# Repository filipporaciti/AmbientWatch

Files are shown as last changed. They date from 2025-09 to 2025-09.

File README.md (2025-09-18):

# 📌 AmbientWatch

## 📖 Descrizione
Il dispositivo permette per monitorare alcuni parametri ambientali (co2, temperatura, umidità, rumore), visualizzarli su un display e mandarli su un server MQTT. È inoltre dotato di un buzzer per segnalare eventuali parametri critici. 

## 🛠️ Hardware utilizzato
- **ESP32**
- **SCD41**: sensore co2, umidità, temperatura
- **INMP441**: microfono
- **SSD1306**: display oled
- **Encoded trigger**
- **Buzzer**
- **Batterie da 3.7V**
- **TP4056**: modulo per caricare le batterie
- **Modulo step-up da 3.7V a 5V**

## 📦 Librerie

```c
#include <Preferences.h>
#include <ESP32Encoder.h>
#include <Wire.h>
#include <Adafruit_SSD1306.h>
#include <Fonts/TomThumb.h>
#include <SensirionI2cScd4x.h>
#include <PubSubClient.h>
#include <WiFi.h>
#include <driver/i2s.h>
#include <Arduino.h>
```

## 🔧 Installazione
⚠️ ATTENZIONE!!! <br>
Il sensore SCD41 potrebbe aver bisogno di essere configurato; in tal caso consultare la libreria [SensirionI2cScd4x](https://github.com/Sensirion/arduino-i2c-scd4x/blob/master/src/SensirionI2cScd4x.h).

Allo stesso modo il microfono potrebbe aver bisogno di essere configurato; in questo caso modificare la costante `DECIBEL_CALIB_OFFSET` nel file [INMP441.h](AmbientWatch/INMP441.h).

Prima di caricare il firmware, bisogna configurare il WiFi e il server MQTT; per farlo basta rinominare il file nella directory [AmbientWatch](AmbientWatch) da `secrets.h.example` a `secrets.h`, aprire il file e impostare correttamente tutti i parametri richiesti.

Una volta configurati tutti i parametri, si può caricare il firmware utilizzando Arduino IDE.

Per quanto riguarda tutti i vari collegamenti, ecco lo schema:

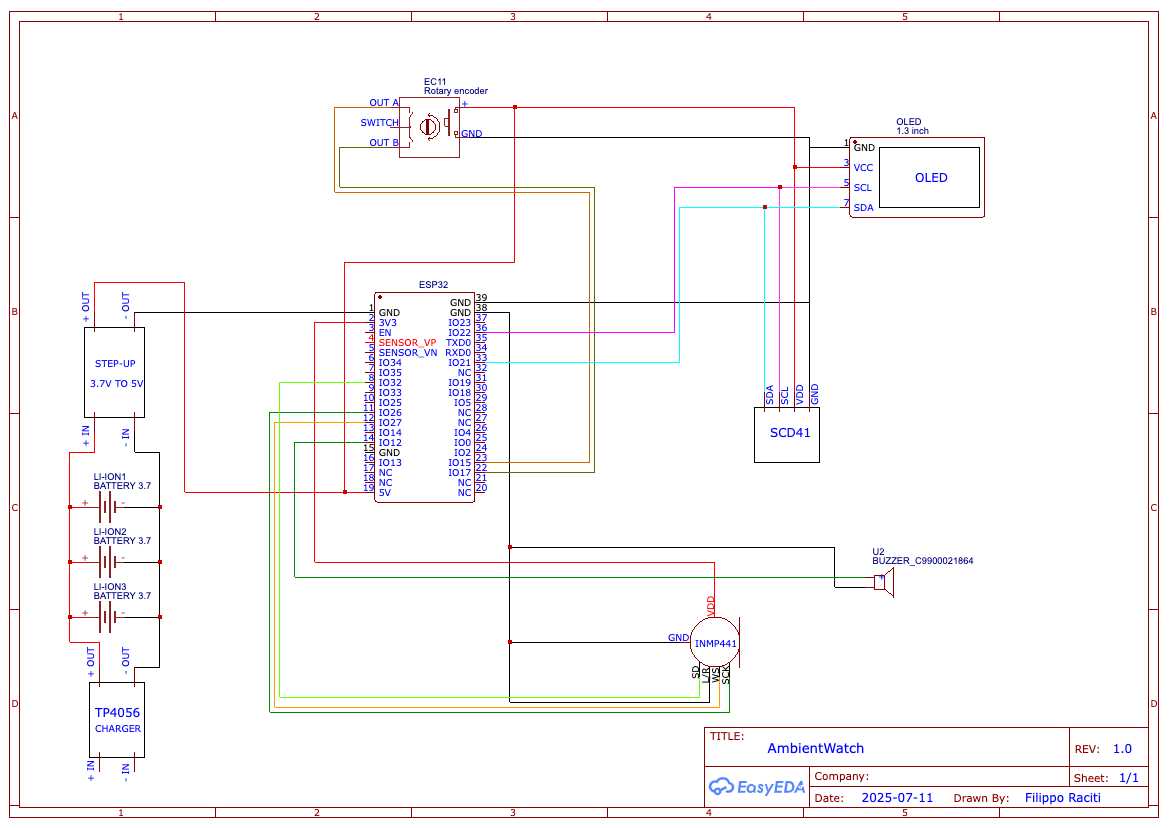
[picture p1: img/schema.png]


## 🔌 Consumo energetico
Facciamo una stima di quanto tempo duri la batteria per alimentare il sistema in maniera continuativa (consideriamo solamente il caso in cui non risvegli l'esp32 dalla sleep mode, ovvero quando non uso l'encoder rotativo per cambiare la schermata del display)

Io ho usato 3 batterie da 1330 mAh l'una.

Il consumo medio del sistema lo possiamo dividere in due fasi:
- Esp32 non in sleep mode: mediamente consuma 90 mA per ~90 s
- Esp32 in sleep mode: consuma 22 mA per ~210 s 
Quindi il consumo medio sarà di $`\dfrac{(90*90)+(22*210)}{300}=42.4`$

Le batterie sono da 1330 mAh l'una, collegate in parallelo --> 3990 mAh.

Quest'ultime erogano una tensione di 3.7V e sono collegate ad uno step-up per alzare e tenere stabile la tensione a 5V. 
Per calcolare il consumo dello step-up dobbiamo trovare la potenza in uscita necessaria con i 5V, e poi verificare la corrente necessaria con i 3.7V. <br>
Inoltre bisogna tenere in considerazione l'efficienza del modulo (circa del 90%) e il suo consumo fisso (2 mA). Quindi: 

Calcolo potenza in uscita dal modulo:<br>
$`P_{out} = 5 V * 0.0424 A ~= 0.212 W`$

Calcolo potenza in entrata dal modulo (quindi devo aggiungere il 10% dato che ha un'efficienza del 90%):<br>
$`P_{in} = 0.212 W + \dfrac{0.212 W * 10}{100} ~= 0.233 W`$

Calcolo corrente entrata con 3.7V:<br>
$`I_{in} = \dfrac{0.233 W}{3.7 V} ~= 0.063 A ~= 63 mA`$

Aggiungo il costo costante del modulo di 2mA:<br>
$`I_{totale} = 63 mA + 2 mA ~= 65 mA`$

**$`Autonomia = \dfrac{3990 mAh}{65 mA} ~= 61.4 h`$**

## ❌ Problemi noti
- Ho dovuto collegare il GND dal modulo step-up all'ESP32 direttamente nello spinotto usb dell'ESP32, altrimenti non sarebbe riuscito a ricevere la corrente necessaria per il suo funzionamento.
- Se uso l'encoded trigger mentre l'ESP32 si trova in light sleep mode, il primo valore catturato dal programma potrebbe non essere quello aspettato; questo accade perchè ESP32  perde delle informazioni per triggerare l'uscita dallo sleep mode.

## 📸 Foto
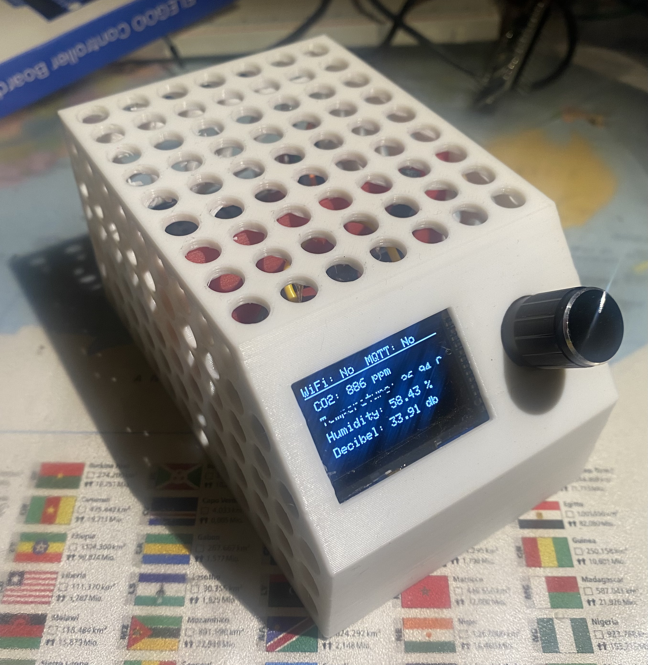
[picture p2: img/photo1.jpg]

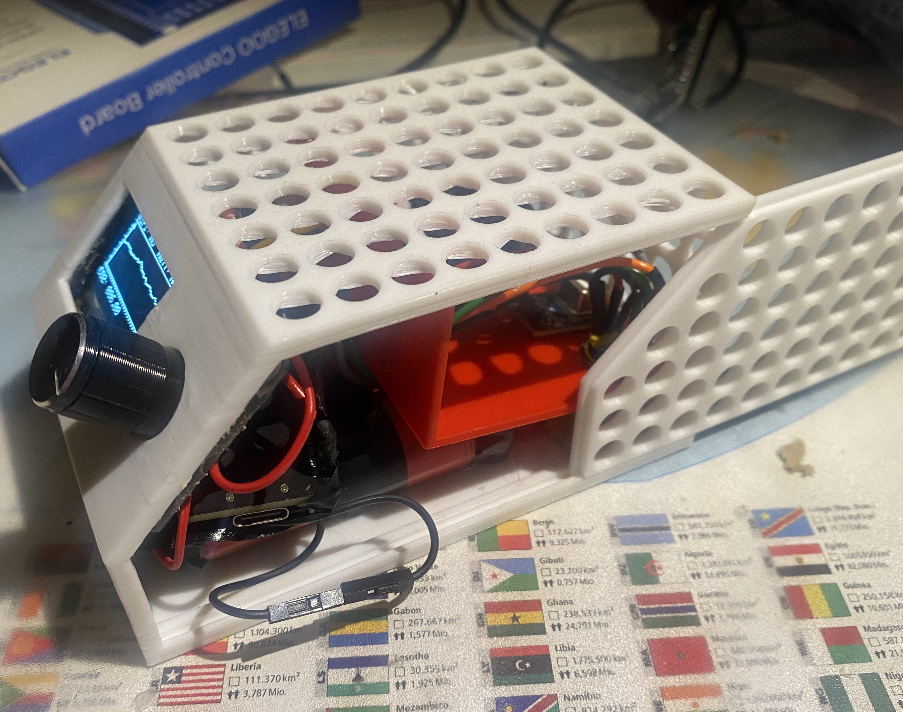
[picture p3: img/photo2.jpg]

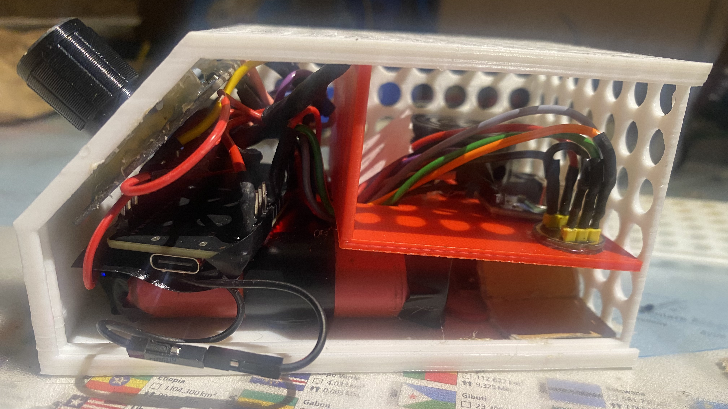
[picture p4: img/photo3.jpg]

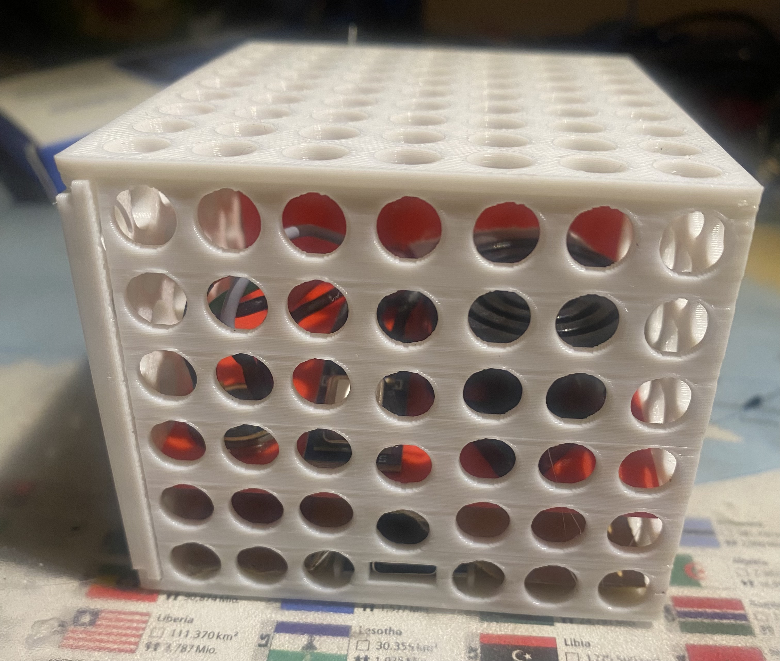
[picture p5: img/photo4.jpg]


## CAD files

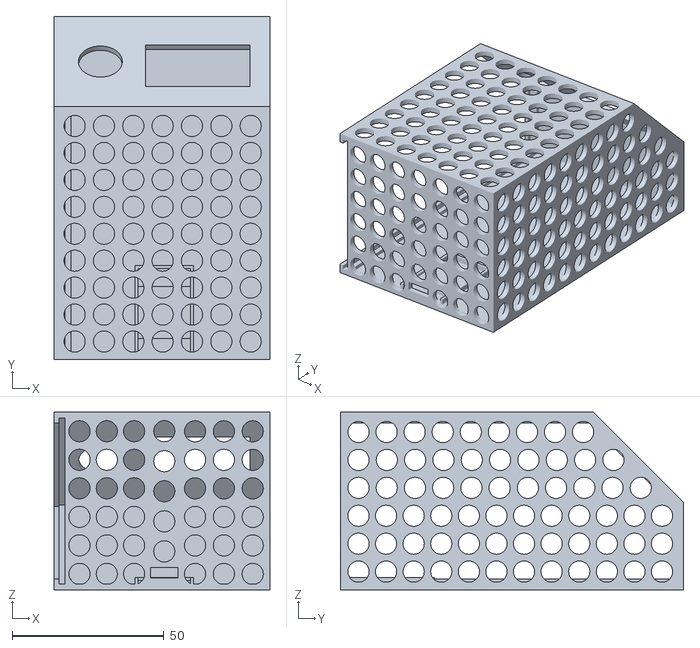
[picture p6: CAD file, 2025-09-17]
case/case.stl
71.0 x 113.0 x 58.5

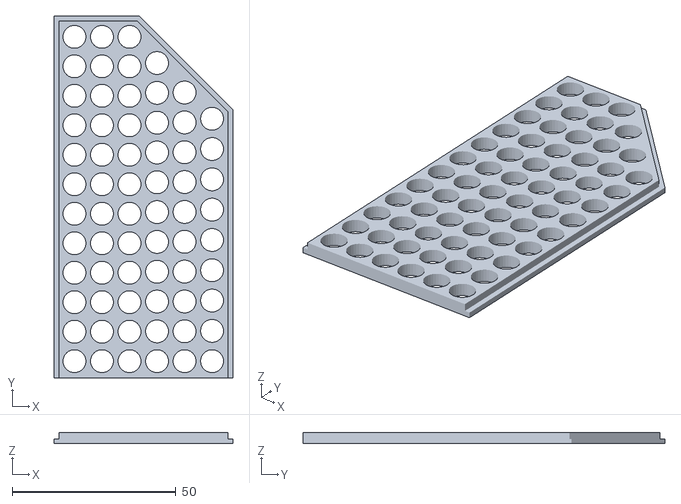
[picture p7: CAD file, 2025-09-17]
case/porta.stl
54.5 x 110.5 x 3.50

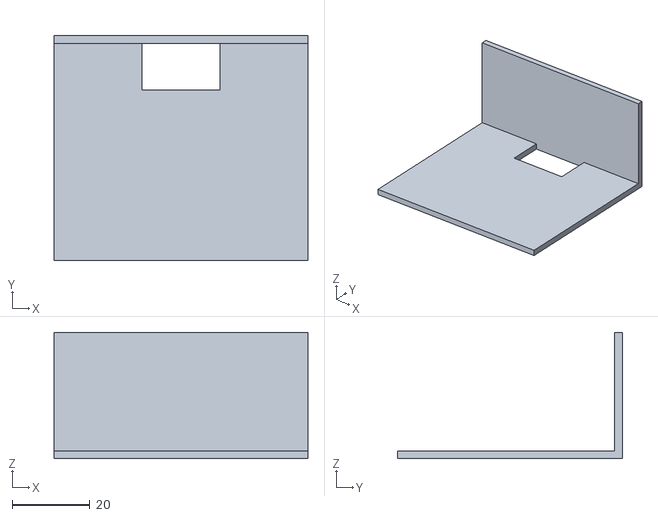
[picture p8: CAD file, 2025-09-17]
case/separatore.stl
65.5 x 58.0 x 32.5

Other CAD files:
case/AmbientWatch_case.f3d

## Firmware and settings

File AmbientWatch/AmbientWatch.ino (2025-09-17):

#include <Preferences.h>
#include <ESP32Encoder.h>
#include <Wire.h>
#include "DataDisplay.h"
#include "WiFi_MQTT.h"
#include "INMP441.h"
#include "SCD41.h"
#include "secrets.h"

#define TRA 15
#define TRB 17
#define BUZZER_PIN 12

#define LIGHT_SLEEP_TIME 60000 * 5

#define MQTT_TOPIC_SUBSCRIBE "esame/pippo/alert_limits/#"
#define MQTT_PUBLISH_ALERT_SOFT "esame/pippo/alert_limits/soft"
#define MQTT_PUBLISH_ALERT_STRONG "esame/pippo/alert_limits/strong"
#define MQTT_PUBLISH_ALERT_STATUS_SOFT "esame/pippo/alert_status/soft"
#define MQTT_PUBLISH_ALERT_STATUS_STRONG "esame/pippo/alert_status/strong"
#define MQTT_PUBLISH_DATA "esame/pippo/data"

TaskHandle_t core0TaskHandle = NULL;

static IRAM_ATTR void resumeDisplayTask(void* arg) {
  if (core0TaskHandle != NULL) {
    vTaskResume(core0TaskHandle);
  }
}

uint16_t co2 = 0;
float temperature = 0.0;
float humidity = 0.0;
float decibel = 0.0;

bool co2_alert = false;
bool temperature_alert = false;
bool humidity_alert = false;
bool decibel_alert = false;

uint16_t soft_co2_max = 0; 
float soft_temp_min = 0;
float soft_temp_max = 0;
float soft_hum_min = 0;
float soft_hum_max = 0;
float soft_dec_max = 0;

uint16_t strong_co2_max = 0; 
float strong_temp_min = 0;
float strong_temp_max = 0;
float strong_hum_min = 0;
float strong_hum_max = 0;
float strong_dec_max = 0;

bool sound_alert = false;

const int numValues = 31;

float co2Values[numValues] = { 0 };
float co2MaxVal = co2;

float tempValues[numValues] = { 0 };
float tempMaxVal = temperature;

float humValues[numValues] = { 0 };
float humMaxVal = humidity;

float decValues[numValues] = { 0 };
float decMaxVal = decibel;

SCD41 sensor;
DataDisplay display;
WiFi_MQTT client(WIFI_SSID, WIFI_PASSWORD, MQTT_IP);
INMP441 decibelSensor;

Preferences prefs;

ESP32Encoder encoder(true, resumeDisplayTask);

long oldPosition = -999;
int encoderValue = 0;

void core0Task(void* parameter) {
  encoderTrigger();
}

void setup() {
  Serial.begin(115200);
  while (!Serial) {
    delay(100);
  }
  Serial.println("");

  loadAlertSettings();
  
  pinMode(BUZZER_PIN, OUTPUT);

  encoder.attachSingleEdge(TRA, TRB);
  encoder.clearCount();

  Wire.begin();

  if (!display.begin()) {
    Serial.println("ERROR: Display begin error");
    for (;;);
  }
  display.clearDisplay(); // stampo schermo nero
  display.display();

  client.connect(MQTT_TOPIC_SUBSCRIBE);
  client.setCallback(callback);
  client.publishAlertLimits(MQTT_PUBLISH_ALERT_SOFT, soft_co2_max, soft_temp_min, soft_temp_max, soft_hum_min, soft_hum_max, soft_dec_max);
  client.publishAlertLimits(MQTT_PUBLISH_ALERT_STRONG, strong_co2_max, strong_temp_min, strong_temp_max, strong_hum_min, strong_hum_max, strong_dec_max);
  client.disconnect();
  
  // lo stampo dopo in questo modo se la batteria è scarica mostra solo lo schermo nero e non quello dei dati lampeggianti
  display.clearDisplay();
  display.printConnectionStatus(false, false);
  display.printValues(co2, temperature, humidity, decibel, false, false, false, false);
  display.display();

  if (!sensor.begin()) {
    Serial.println("ERROR: SCD41 sensor error begin");
    for (;;);
  }

  xTaskCreatePinnedToCore(
    core0Task,         // nome funzione
    "core0Task",       // nome task
    4096,              // grandezza stack
    NULL,              // parametri
    1,                 // priorità
    &core0TaskHandle,  // handle
    0                  // Core 0
  );

}

void loop() {
  Serial.println("----- Start loop -----");

  unsigned long mill_start = millis();

  // ----- Reading data -----
  Serial.print("Reading co2, temperature, humidity values...");
  sensor.getValues(co2, temperature, humidity);
  pushInCoda(co2Values, (float)co2, numValues);
  pushInCoda(tempValues, temperature, numValues);
  pushInCoda(humValues, humidity, numValues);
  if (tempMaxVal < temperature) {
    tempMaxVal = temperature;
  }
  if (co2MaxVal < co2) {
    co2MaxVal = co2;
  }
  if (humMaxVal < humidity) {
    humMaxVal = humidity;
  }
  Serial.println("end");

  Serial.print("Reading decibel...");
  decibel = decibelSensor.readAvgValue();
  pushInCoda(decValues, decibel, numValues);
  if (decMaxVal < decibel) {
    decMaxVal = decibel;
  }
  Serial.println("end");

  Serial.print("CO2: ");
  Serial.print(co2);
  Serial.println(" ppm");

  Serial.print("Environment temperature : ");
  Serial.print(temperature);
  Serial.println(" C");

  Serial.print("Relative humidity : ");
  Serial.print(humidity);
  Serial.println(" RH");

  Serial.print("Decibel : ");
  Serial.print(decibel);
  Serial.println(" db");
  // ----- End reading data -----

  checkValues();

  // ----- MQTT -----
  client.connect(MQTT_TOPIC_SUBSCRIBE);
  client.publishData(MQTT_PUBLISH_DATA, co2, temperature, humidity, decibel);
  client.updateSubscribe();
  saveAlertSettings(); // se ci sono stati aggironamenti, li salvo
  // client.publishSoftAlertLimits(soft_co2_max, soft_temp_min, soft_temp_max, soft_hum_min, soft_hum_max, soft_dec_max); // potrei metterli per eliminare i retain
  // client.publishStrongAlertLimits(strong_co2_max, strong_temp_min, strong_temp_max, strong_hum_min, strong_hum_max, strong_dec_max);
  client.publishAlertStatus(MQTT_PUBLISH_ALERT_STATUS_SOFT, co2_alert || temperature_alert || humidity_alert || decibel_alert);
  client.publishAlertStatus(MQTT_PUBLISH_ALERT_STATUS_STRONG, sound_alert);
  client.disconnect();
  // ----- End MQTT -----

  updateDisplay();

  if (!(co2_alert || temperature_alert || humidity_alert || decibel_alert || sound_alert)) {  // se non ho alert allora posso andare il sleep, altrimenti aggiorno i valori
    while (eTaskGetState(core0TaskHandle) != eSuspended) { // aspetta che il task abbia finito
      delay(70);
    }
    unsigned long m = millis();
    unsigned long sleep_time = LIGHT_SLEEP_TIME - (m - mill_start);
    if (sleep_time < 0 || sleep_time > LIGHT_SLEEP_TIME) {
      sleep_time = LIGHT_SLEEP_TIME;
    }
    anyway_sleep_timer(sleep_time);
  }
}

/*
Fa andare l'esp32 in light sleep mode per il tempo impostato dal parametro time_sleep. 
L'esp32 può uscire dalla sleep mode attraverso un interrupt oppure quando il tempo è terminato.
In caso l'esp32 esca dalla sleep mode attraverso l'interrupt, la funzione si occuperà di rimettere l'esp32 in sleep mode appena possibile fino alla fine del tempo prestabilito.

@param time_sleep tempo in cui l'esp32 dovrà stare in sleep mode
*/
void anyway_sleep_timer(unsigned long time_sleep) {
  unsigned long m_start = 0;
  unsigned long time_left = time_sleep;

  while (time_left > 1000) {  // qualche millisecondo di range per evitare falsi positivi
    Serial.print("Light sleep mode. Time left: ");
    Serial.println(time_left);
    Serial.flush();

    m_start = millis();
    esp_sleep_enable_ext0_wakeup(GPIO_NUM_15, 0);
    esp_sleep_enable_timer_wakeup(time_left * 1000);  // vuole microsecondi come parametro
    esp_light_sleep_start();

    resumeDisplayTask(NULL);
    while (eTaskGetState(core0TaskHandle) != eSuspended) { // aspetta che il task abbia finito
      delay(70);
      m_start += 70;
    }

    unsigned long m_now = millis();
    unsigned long sleep = time_left - (m_now - m_start);  // vedo quanto è passato
    if (time_left < m_now - m_start) {
      sleep = 0;
    }

    if (sleep > time_left || m_now < m_start) {  // per eventuali overflow
      Serial.println("Timer reset");
      time_left = 0;
    } else {
      time_left = sleep;
    }
  }
}

/*
Serve per gestire l'encoder e l'aggiornamento del display.
*/
void encoderTrigger() {
  while (true) {
    unsigned long encoderTime = millis();

    while (millis() - encoderTime < 1000) {
      long newPosition = encoder.getCount();
      if (newPosition != oldPosition) {
        encoderTime = millis(); // resetto il tempo di fine task (se non ci sono valori critici)
        oldPosition = newPosition;
        encoderValue = newPosition;
        if (encoderValue < 0) { // il modulo di un numero negativo lo tratta come se fosse positivo :(
          int x = (abs(encoderValue)/5)+1;
          encoderValue += 5*x;
        }
        encoderValue = (encoderValue) % 5;
        Serial.print("Display position: ");
        Serial.println(encoderValue);
        // il display devo aggiornarlo almeno una volta, e in caso ci sia un alert tutte le volte finchè non termina l'alert
        do {
          if (co2_alert || temperature_alert || humidity_alert || decibel_alert) encoderValue = 0;
          checkValues();
          printDisplay();
        } while (co2_alert || temperature_alert || humidity_alert || decibel_alert);
      }
      yield();  // per evitare il watchdog. yield permette di lasciare la CPU ad altri task
    }
    Serial.println("Display task suspend");
    vTaskSuspend(core0TaskHandle);
    Serial.println("Display task resume");
  }
}

/*
Aggiorna il display.
*/
void updateDisplay() {
  oldPosition = -999;
  resumeDisplayTask(NULL);
}

/*
Visualizza le informazioni nel display in base al valore dell'encoder in quel momento.
*/
void printDisplay() {
  display.clearDisplay();
  display.printConnectionStatus(client.wifiStatus, client.mqttStatus);
  if (encoderValue == 0) {
    display.printValues(co2, temperature, humidity, decibel, co2_alert, temperature_alert, humidity_alert, decibel_alert);
  } else if (encoderValue == 1) {
    display.printGraph("Decibel: ", decValues, numValues, decMaxVal);
  } else if (encoderValue == 2) {
    display.printGraph("Humidity: ", humValues, numValues, humMaxVal);
  } else if (encoderValue == 3) {
    display.printGraph("Temperature: ", tempValues, numValues, tempMaxVal);
  } else if (encoderValue == 4) {
    display.printGraph("CO2: ", co2Values, numValues, co2MaxVal);
  } else {
    display.clearDisplay();
    display.display();
  }
}

/*
Dato un'array, la funzione mette l'elemento in posizione i nella posizione i-1.
L'elemento in posizione 0 verrà eliminato mentre l'elemento nell'ultima posizione sarà il parametro newVal.

@param arr array da modificare
@param newVal nuovo valore che verrà posizionato in posizione len-1
@param len lunghezza array
*/
void pushInCoda(float* arr, float newVal, int len) {
  for (int i = 0; i < len - 1; i++) {
    arr[i] = arr[i + 1];
  }
  arr[len - 1] = newVal;
}

/*
Controlla che i valori non superino i soft e strong limit e imposta le variabili degli alert a true se li supera, altrimenti a false. 
La funzione inoltre attiva e disattiva il buzzer in caso i valori superino gli strong limit.
*/
void checkValues() {
  if (co2 != 0 && temperature != 0 && humidity != 0) { // in caso non siano stati presi i valori, non faccio il check dei valori
    co2_alert = co2 > soft_co2_max;
    temperature_alert = temperature < soft_temp_min || temperature > soft_temp_max;
    humidity_alert = humidity < soft_hum_min || humidity > soft_hum_max;
    decibel_alert = decibel > soft_dec_max;
    sound_alert = co2 > strong_co2_max || temperature < strong_temp_min || temperature > strong_temp_max || humidity < strong_hum_min || humidity > strong_hum_max;
    if (sound_alert) {
      digitalWrite(BUZZER_PIN, HIGH); 
    } else {
      digitalWrite(BUZZER_PIN, LOW);    
    }
  }
}

/*
Salva in maniera persistente i soft e strong limit dalle variabili corrispondenti.
*/
void saveAlertSettings() {
  prefs.begin("AmbientWatch", false); // false = scrittura

  prefs.putUShort("soft_co2_max", soft_co2_max);
  prefs.putFloat("soft_temp_min", soft_temp_min);
  prefs.putFloat("soft_temp_max", soft_temp_max);
  prefs.putFloat("soft_hum_min", soft_hum_min);
  prefs.putFloat("soft_hum_max", soft_hum_max);
  prefs.putFloat("soft_dec_max", soft_dec_max);

  prefs.putUShort("strong_co2_max", strong_co2_max);
  prefs.putFloat("strong_temp_min", strong_temp_min);
  prefs.putFloat("strong_temp_max", strong_temp_max);
  prefs.putFloat("strong_hum_min", strong_hum_min);
  prefs.putFloat("strong_hum_max", strong_hum_max);
  prefs.putFloat("strong_dec_max", strong_dec_max);

  prefs.end();
  Serial.println("Save alert settings");
}

/*
Carica dalla memoria i soft e strong limit e li mette nelle variabili corrispondenti. In caso non ci siano, saranno caricati dei valori di default.
*/
void loadAlertSettings() {
  prefs.begin("AmbientWatch", true); // true = lettura

  soft_co2_max = prefs.getUShort("soft_co2_max", 2000);
  soft_temp_min = prefs.getFloat("soft_temp_min", 19);
  soft_temp_max = prefs.getFloat("soft_temp_max", 30);
  soft_hum_min = prefs.getFloat("soft_hum_min", 30);
  soft_hum_max = prefs.getFloat("soft_hum_max", 70);
  soft_dec_max = prefs.getFloat("soft_dec_max", 70);

  strong_co2_max = prefs.getUShort("strong_co2_max", 5000);
  strong_temp_min = prefs.getFloat("strong_temp_min", 10);
  strong_temp_max = prefs.getFloat("strong_temp_max", 37);
  strong_hum_min = prefs.getFloat("strong_hum_min", 15);
  strong_hum_max = prefs.getFloat("strong_hum_max", 90);
  strong_dec_max = prefs.getFloat("strong_dec_max", 120);

  prefs.end();
  Serial.println("Load alert settings");
}

/*
Questa funzione verrà richiamata ogni volta che l'esp32 riceve un messaggio a cui aveva fatto il subscribe. 
La funzione individua il topic e salva il valore del payload nella variabile corrispondente (serve per modificare i valori dei limiti).
*/
void callback(char* topic, byte* payload, unsigned int length) {
  Serial.print("subscribe: Message arrived [");
  Serial.print(topic);
  Serial.print("] ");

  String message;
  for (unsigned int i = 0; i < length; i++) {
    message += (char)payload[i];
  }

  Serial.println(message);

  if (strcmp(topic, MQTT_PUBLISH_ALERT_SOFT "/co2_max") == 0) {
    soft_co2_max = message.toInt();
  }
  if (strcmp(topic, MQTT_PUBLISH_ALERT_SOFT "/temp_min") == 0) {
    soft_temp_min = message.toFloat();
  }
  if (strcmp(topic, MQTT_PUBLISH_ALERT_SOFT "/temp_max") == 0) {
    soft_temp_max = message.toFloat();
  }
  if (strcmp(topic, MQTT_PUBLISH_ALERT_SOFT "/hum_min") == 0) {
    soft_hum_min = message.toFloat();
  }
  if (strcmp(topic, MQTT_PUBLISH_ALERT_SOFT "/hum_max") == 0) {
    soft_hum_max = message.toFloat();
  }
  if (strcmp(topic, MQTT_PUBLISH_ALERT_SOFT "/dec_max") == 0) {
    soft_dec_max = message.toFloat();
  }

  if (strcmp(topic, MQTT_PUBLISH_ALERT_STRONG "/co2_max") == 0) {
    strong_co2_max = message.toInt();
  }
  if (strcmp(topic, MQTT_PUBLISH_ALERT_STRONG "/temp_min") == 0) {
    strong_temp_min = message.toFloat();
  }
  if (strcmp(topic, MQTT_PUBLISH_ALERT_STRONG "/temp_max") == 0) {
    strong_temp_max = message.toFloat();
  }
  if (strcmp(topic, MQTT_PUBLISH_ALERT_STRONG "/hum_min") == 0) {
    strong_hum_min = message.toFloat();
  }
  if (strcmp(topic, MQTT_PUBLISH_ALERT_STRONG "/hum_max") == 0) {
    strong_hum_max = message.toFloat();
  }
  if (strcmp(topic, MQTT_PUBLISH_ALERT_STRONG "/dec_max") == 0) {
    strong_dec_max = message.toFloat();
  }
}

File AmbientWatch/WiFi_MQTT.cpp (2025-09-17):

#include "WiFi_MQTT.h"
#include <PubSubClient.h>
#include <WiFi.h>

WiFi_MQTT::WiFi_MQTT(const char *SSID, const char *password, const char *mqttServer, int mqttPort): PubSubClient(_wifiClient) {
  _ssid = SSID;
  _password = password;
  _mqttServer = mqttServer;
  _mqttPort = mqttPort;
  PubSubClient::setServer(_mqttServer, _mqttPort);
}


bool WiFi_MQTT::publishData(String topicPrefix, uint16_t co2, float temperature, float humidity, float decibel) {

  bool ris = PubSubClient::connected();

  if (ris) {
    char msg[16];

    // CO2
    snprintf(msg, sizeof(msg), "%u", co2);
    PubSubClient::publish((topicPrefix + "/co2").c_str(), msg, true);

    // Temperatura
    snprintf(msg, sizeof(msg), "%.2f", temperature);
    PubSubClient::publish((topicPrefix + "/temperature").c_str(), msg, true);

    // Umidità
    snprintf(msg, sizeof(msg), "%.2f", humidity);
    PubSubClient::publish((topicPrefix + "/humidity").c_str(), msg, true);

    // // Decibel
    snprintf(msg, sizeof(msg), "%.2f", decibel);
    PubSubClient::publish((topicPrefix + "/decibel").c_str(), msg, true);
  }

  Serial.println("MQTT publish data");
  mqttStatus = ris;
  return ris;
}

bool WiFi_MQTT::publishAlertLimits(String topicPrefix, uint16_t co2_max, float temp_min, float temp_max, float hum_min, float hum_max, float dec_max) {

  bool ris = PubSubClient::connected();

  if (ris) {
    char msg[16];

    // CO2 minimo
    snprintf(msg, sizeof(msg), "%u", co2_max);
    PubSubClient::publish((topicPrefix + "/co2_max").c_str(), msg, true);

    // Temperatura minima
    snprintf(msg, sizeof(msg), "%.2f", temp_min);
    PubSubClient::publish((topicPrefix + "/temp_min").c_str(), msg, true);

    // Temperatura massima
    snprintf(msg, sizeof(msg), "%.2f", temp_max);
    PubSubClient::publish((topicPrefix + "/temp_max").c_str(), msg, true);

    // Umidità minima
    snprintf(msg, sizeof(msg), "%.2f", hum_min);
    PubSubClient::publish((topicPrefix + "/hum_min").c_str(), msg, true);

    // Umidità massima
    snprintf(msg, sizeof(msg), "%.2f", hum_max);
    PubSubClient::publish((topicPrefix + "/hum_max").c_str(), msg, true);

    // Decibel minimo
    snprintf(msg, sizeof(msg), "%.2f", dec_max);
    PubSubClient::publish((topicPrefix + "/dec_max").c_str(), msg, true);
  }

  Serial.println("MQTT publish alert limits");
  mqttStatus = ris;
  return ris;
}

bool WiFi_MQTT::publishAlertStatus(String topic, bool active) {

  bool ris = PubSubClient::connected();

  if (ris) {
    PubSubClient::publish(topic.c_str(), active ? "1" : "0", true);
  }

  Serial.println("MQTT publish alert status");
  mqttStatus = ris;
  return ris;
}

bool WiFi_MQTT::updateSubscribe(){

  bool ris = PubSubClient::connected();
  if (ris) {
    for (int i=0; i<10; i++) {
      PubSubClient::loop();
      delay(10);
    }
  }
  mqttStatus = ris;
  return ris;
}


bool WiFi_MQTT::mqttConnect(const char* topic) {
  if (PubSubClient::connected()){
    return true;
  }
  for (int i=0; i<3; i++) {
    Serial.print("Attempting MQTT connection...");
    if (PubSubClient::connect("Pippo")) {
      Serial.println("connected");
      PubSubClient::subscribe(topic);
      return true;
    } else {
      Serial.println("Try again in 5 seconds");
      delay(3000); // Wait 3 seconds before retrying
    }
  }
  return false;
}


void WiFi_MQTT::wifiDisconnect() {
  if (WiFi.isConnected()) {
    WiFi.disconnect();
    WiFi.mode(WIFI_OFF);
    Serial.println("WiFi disconnect");
  }
}

bool WiFi_MQTT::wifiConnect() {
  if (WiFi.status() != WL_CONNECTED) {
    WiFi.mode(WIFI_STA);
    WiFi.begin(_ssid, _password);

    Serial.println();
    Serial.print("Connecting");
    for (int i=0; i<30; i++) {
      if (WiFi.status() == WL_CONNECTED) {
        break;
      }
      delay(500);
      Serial.print(".");
    }
    
    if (WiFi.status() == WL_CONNECTED) {
      Serial.println();
      Serial.print("Connected, IP address: ");
      Serial.println(WiFi.localIP());
    } else {
      Serial.println();
      Serial.println("WiFi not connected");
    }
    
    wifiStatus = WiFi.status() == WL_CONNECTED;
  }
  return WiFi.status() == WL_CONNECTED;
}

void WiFi_MQTT::disconnect() {
  PubSubClient::disconnect();
  wifiDisconnect();
}

bool WiFi_MQTT::connect(const char* topic) {
  bool ris = wifiConnect();
  if (!ris) {
    return false;
  }
  return mqttConnect(topic);
}
